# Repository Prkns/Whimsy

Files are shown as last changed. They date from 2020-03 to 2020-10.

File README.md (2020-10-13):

# Whimsy - Rev0.21

A 40% keyboard with exposed Elite-C/OLED and Rotary encoder.

My first attempt at designing a "proper" custom keyboard. I spent far too long looking at all the amazing new PCB's and custom keyboards being released and having a massive urge to do one for myself. Here is my first attempt.

I've not taken delivery of the physical PCBs as of yet so i can't comment on how well i did, but they will be with me shortly.

**STILL IN DEVELOPMENT - NOT READY FOR PRODUCTION - DO NOT ORDER**

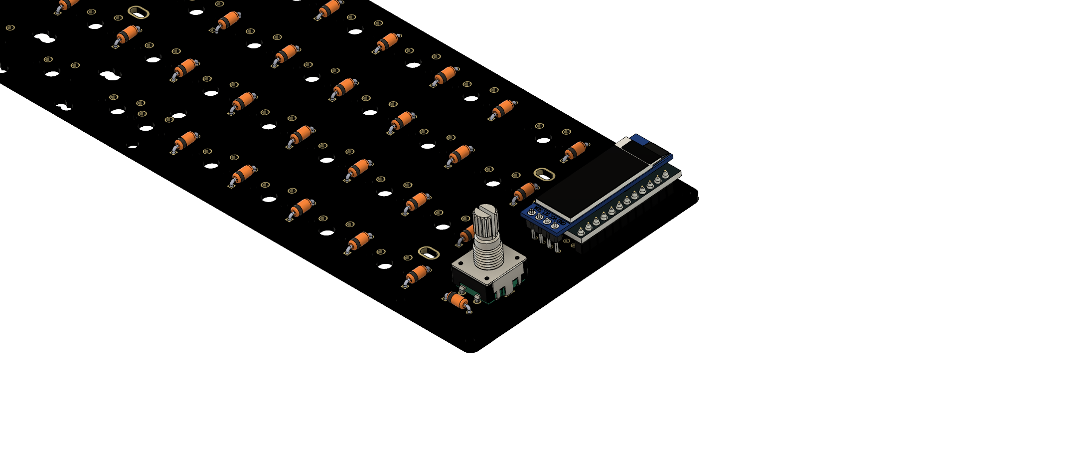
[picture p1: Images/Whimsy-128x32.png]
Whimsy


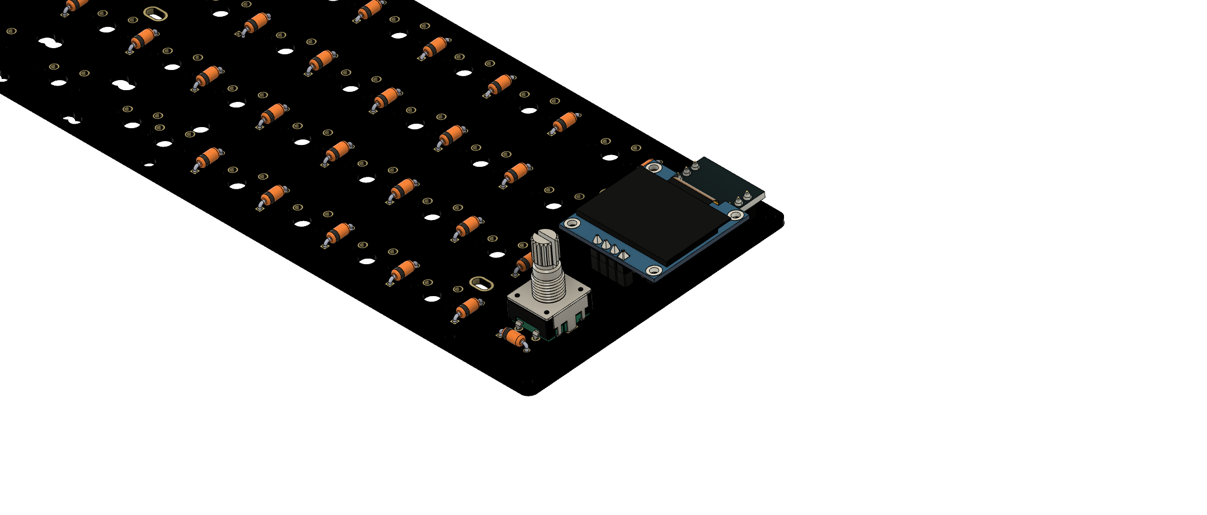
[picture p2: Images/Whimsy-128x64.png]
Whimsy


---

### Plans 🤔

**rev1:** A working version of the board and an FR4 sandwich case

**rev2:** Tidied up traces and an acrylic case

---

#### Say hi 👋

If you're interested in any aspect of this board or want to point out anything that could be done better in a more private manner, head on over to my [website](https://prkns.me/) and you'll find a few different methods on there.

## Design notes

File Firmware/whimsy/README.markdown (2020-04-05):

# Whimsy!



Whimsy is the Most Extra 40% keyboard I could think of. It is designed by [David Perkins](https://prkns.me/), who apparently takes every ridiculous idea
as a personal challenge. The layout is currently based heavily on the incredible UT47.2, but with an added rotary encoder, and OLED.

## Updates

### 2020-03-16
v0 PCBs have arrived and are awaiting additional supplies to be built and tested.

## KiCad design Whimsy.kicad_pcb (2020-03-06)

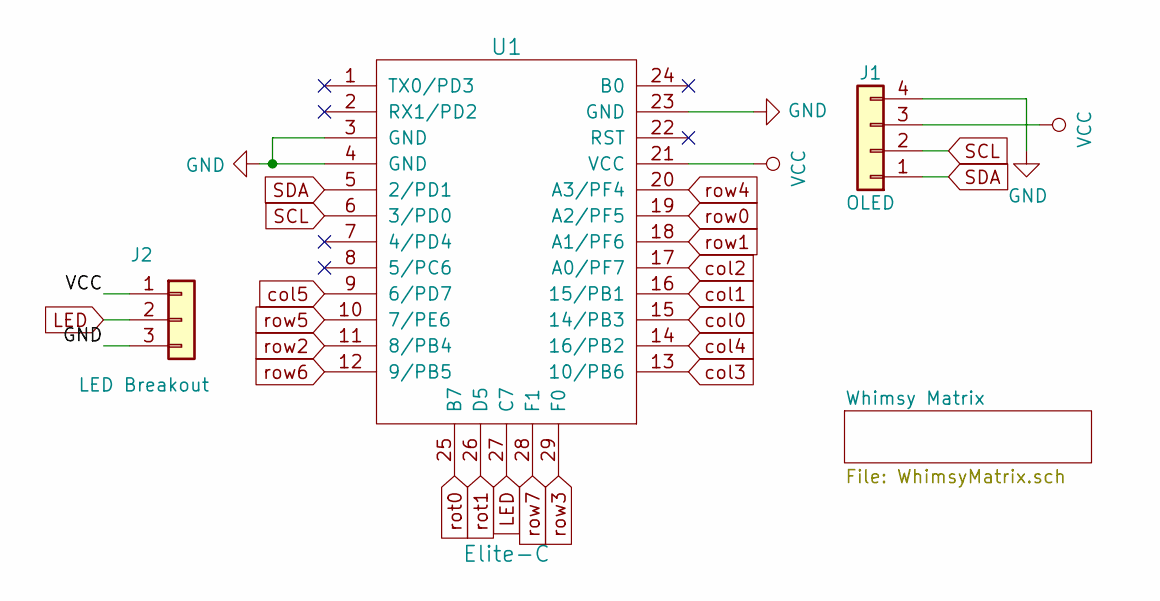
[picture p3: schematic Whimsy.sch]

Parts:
J1: OLED; OLED_4Pin
J2: LED Breakout; LED
U1: Elite-C; Elite-C-NoSilk

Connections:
GND: J1.4, J2.3, U1.3 (GND), U1.4 (GND), U1.23 (GND); also elsewhere on the board
LED: J2.2, U1.27 (C7)
SCL: J1.2, U1.6 (3/PD0)
SDA: J1.1, U1.5 (2/PD1)
VCC: J1.3, J2.1, U1.21 (VCC)
col0: U1.15 (14/PB3); also elsewhere on the board
col1: U1.16 (15/PB1); also elsewhere on the board
col2: U1.17 (A0/PF7); also elsewhere on the board
col3: U1.13 (10/PB6); also elsewhere on the board
col4: U1.14 (16/PB2); also elsewhere on the board
col5: U1.9 (6/PD7); also elsewhere on the board
rot0: U1.25 (B7); also elsewhere on the board
rot1: U1.26 (D5); also elsewhere on the board
row0: U1.19 (A2/PF5); also elsewhere on the board
row1: U1.18 (A1/PF6); also elsewhere on the board
row2: U1.11 (8/PB4); also elsewhere on the board
row3: U1.29 (F0); also elsewhere on the board
row4: U1.20 (A3/PF4); also elsewhere on the board
row5: U1.10 (7/PE6); also elsewhere on the board
row6: U1.12 (9/PB5); also elsewhere on the board
row7: U1.28 (F1); also elsewhere on the board

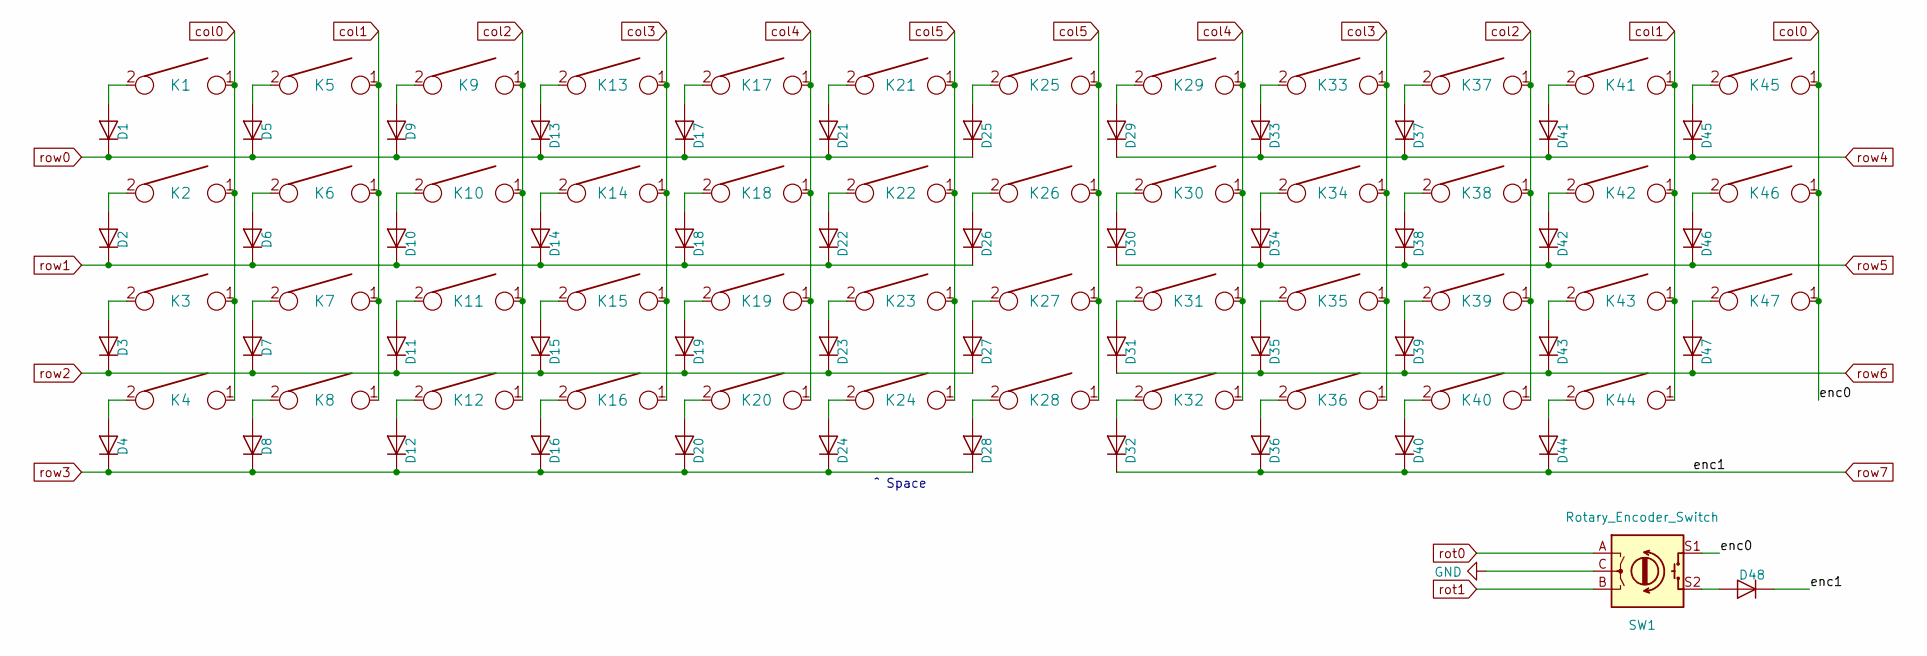
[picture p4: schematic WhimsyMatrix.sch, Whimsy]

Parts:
D1, D2, D3, D4, D5, D6, D7, D8, D9, D10, D11, D12, D13, D14, D15, D16, D17, D18, D19, D20, D21, D22, D23, D24, D25, D26, D27, D28, D29, D30, D31, D32, D33, D34, D35, D36, D37, D38, D39, D40, D41, D42, D43, D44, D45, D46, D47, D48: D; Diode-Hybrid-Back
K1, K4, K5, K6, K7, K8, K9, K10, K11, K12, K13, K14, K15, K16, K17, K18, K19, K21, K22, K23, K25, K26, K27, K29, K30, K31, K32, K33, K34, K35, K36, K37, K38, K39, K40, K41, K42, K43, K44, K47: KEYSW; Mx_Alps_100
K2, K20, K28, K46: KEYSW; Mx_Alps_125
K3, K45: KEYSW; Mx_Alps_150
K24: KEYSW; Mx_Alps_200
SW1: Rotary_Encoder_Switch; RotaryEncoder_Alps_EC11E-Switch_Vertical_H20mm-keebio_modif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

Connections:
GND: SW1.C; also elsewhere on the board
unnamed: D1.2 (A), K1.2
unnamed: D2.2 (A), K2.2
unnamed: D3.2 (A), K3.2
unnamed: D4.2 (A), K4.2
unnamed: D5.2 (A), K5.2
unnamed: D6.2 (A), K6.2
unnamed: D7.2 (A), K7.2
unnamed: D8.2 (A), K8.2
unnamed: D9.2 (A), K9.2
unnamed: D10.2 (A), K10.2
unnamed: D11.2 (A), K11.2
unnamed: D12.2 (A), K12.2
unnamed: D13.2 (A), K13.2
unnamed: D14.2 (A), K14.2
unnamed: D15.2 (A), K15.2
unnamed: D16.2 (A), K16.2
unnamed: D17.2 (A), K17.2
unnamed: D18.2 (A), K18.2
unnamed: D19.2 (A), K19.2
unnamed: D20.2 (A), K20.2
unnamed: D21.2 (A), K21.2
unnamed: D22.2 (A), K22.2
unnamed: D23.2 (A), K23.2
unnamed: D24.2 (A), K24.2
unnamed: D25.2 (A), K25.2
unnamed: D26.2 (A), K26.2
unnamed: D27.2 (A), K27.2
unnamed: D28.2 (A), K28.2
unnamed: D29.2 (A), K29.2
unnamed: D30.2 (A), K30.2
unnamed: D31.2 (A), K31.2
unnamed: D32.2 (A), K32.2
unnamed: D33.2 (A), K33.2
unnamed: D34.2 (A), K34.2
unnamed: D35.2 (A), K35.2
unnamed: D36.2 (A), K36.2
unnamed: D37.2 (A), K37.2
unnamed: D38.2 (A), K38.2
unnamed: D39.2 (A), K39.2
unnamed: D40.2 (A), K40.2
unnamed: D41.2 (A), K41.2
unnamed: D42.2 (A), K42.2
unnamed: D43.2 (A), K43.2
unnamed: D44.2 (A), K44.2
unnamed: D45.2 (A), K45.2
unnamed: D46.2 (A), K46.2
unnamed: D47.2 (A), K47.2
unnamed: D48.2 (A), SW1.S2
col0: K1.1, K2.1, K3.1, K4.1, K45.1, K46.1, K47.1, SW1.S1; also elsewhere on the board
col1: K5.1, K6.1, K7.1, K8.1, K41.1, K42.1, K43.1, K44.1; also elsewhere on the board
col2: K9.1, K10.1, K11.1, K12.1, K37.1, K38.1, K39.1, K40.1; also elsewhere on the board
col3: K13.1, K14.1, K15.1, K16.1, K33.1, K34.1, K35.1, K36.1; also elsewhere on the board
col4: K17.1, K18.1, K19.1, K20.1, K29.1, K30.1, K31.1, K32.1; also elsewhere on the board
col5: K21.1, K22.1, K23.1, K24.1, K25.1, K26.1, K27.1, K28.1; also elsewhere on the board
rot0: SW1.A; also elsewhere on the board
rot1: SW1.B; also elsewhere on the board
row0: D1.1 (K), D5.1 (K), D9.1 (K), D13.1 (K), D17.1 (K), D21.1 (K), D25.1 (K); also elsewhere on the board
row1: D2.1 (K), D6.1 (K), D10.1 (K), D14.1 (K), D18.1 (K), D22.1 (K), D26.1 (K); also elsewhere on the board
row2: D3.1 (K), D7.1 (K), D11.1 (K), D15.1 (K), D19.1 (K), D23.1 (K), D27.1 (K); also elsewhere on the board
row3: D4.1 (K), D8.1 (K), D12.1 (K), D16.1 (K), D20.1 (K), D24.1 (K), D28.1 (K); also elsewhere on the board
row4: D29.1 (K), D33.1 (K), D37.1 (K), D41.1 (K), D45.1 (K); also elsewhere on the board
row5: D30.1 (K), D34.1 (K), D38.1 (K), D42.1 (K), D46.1 (K); also elsewhere on the board
row6: D31.1 (K), D35.1 (K), D39.1 (K), D43.1 (K), D47.1 (K); also elsewhere on the board
row7: D32.1 (K), D36.1 (K), D40.1 (K), D44.1 (K), D48.1 (K); also elsewhere on the board

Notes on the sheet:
^ Space

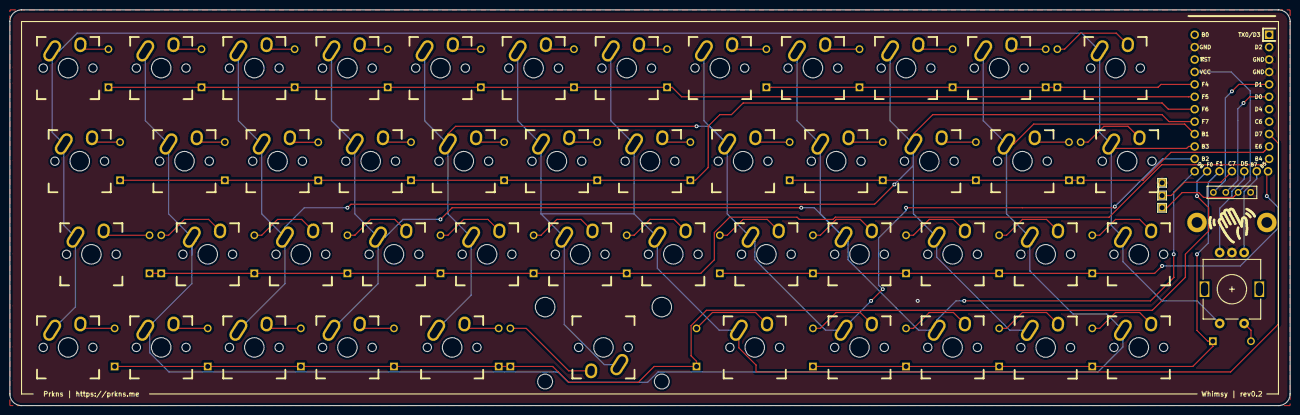
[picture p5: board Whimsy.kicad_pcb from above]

Board: 2 copper layers, 261.9 x 81.0 mm, 102 parts (1 on the bottom side), 69 nets.

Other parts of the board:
TH1, TH1#2: HOLE; M2_HOLE_PCB
Wave: Wave

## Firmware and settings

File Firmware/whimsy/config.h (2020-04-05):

#ifndef CONFIG_H
#define CONFIG_H

#include "config_common.h"

/* USB Device descriptor parameter */
#define VENDOR_ID       0xFEED
#define PRODUCT_ID      0x6060
#define DEVICE_VER      0x0001
#define MANUFACTURER    qmkbuilder
#define PRODUCT         keyboard
#define DESCRIPTION     Keyboard

/* key matrix size */
#define MATRIX_ROWS 8
#define MATRIX_COLS 6

#define ENCODER_RESOLUTION 2
#define ENCODERS_PAD_A { D5 }
#define ENCODERS_PAD_B { B7 }

/* key matrix pins */
#define MATRIX_ROW_PINS { F5, F6, B4, F0, F4, E6, B5, F1 }
#define MATRIX_COL_PINS { B3, B1, F7, B6, B2, D7 }
#define UNUSED_PINS

/* COL2ROW or ROW2COL */
#define DIODE_DIRECTION COL2ROW

/* number of backlight levels */

#ifdef BACKLIGHT_PIN
#define BACKLIGHT_LEVELS 3
#endif

/* Set 0 if debouncing isn't needed */
#define DEBOUNCING_DELAY 5

/* Mechanical locking support. Use KC_LCAP, KC_LNUM or KC_LSCR instead in keymap */
#define LOCKING_SUPPORT_ENABLE

/* Locking resynchronize hack */
#define LOCKING_RESYNC_ENABLE

/* key combination for command */
#define IS_COMMAND() ( \
    keyboard_report->mods == (MOD_BIT(KC_LSHIFT) | MOD_BIT(KC_RSHIFT)) \
)

/* prevent stuck modifiers */
#define PREVENT_STUCK_MODIFIERS

#define RGB_DI_PIN C7
#ifdef RGB_DI_PIN
#define RGBLIGHT_ANIMATIONS
#define RGBLED_NUM 8
#define RGBLIGHT_HUE_STEP 8
#define RGBLIGHT_SAT_STEP 8
#define RGBLIGHT_VAL_STEP 8
#endif

#endif

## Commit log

2020-03-03 added elite-c, changed switch matrix to groups, added LED breakout, added off board reset switch, added OLED pins
    [Whimsy.sch, WhimsyMatrix.sch]
2020-03-03 duplicate diode (D28) fixed
    [Whimsy.sch, WhimsyMatrix.sch]
2020-03-03 first layout test
    [Whimsy.sch, WhimsyMatrix.sch]
2020-03-04 properly laid out keys, cut edges
    [Whimsy.kicad_pcb, WhimsyMatrix.sch]
2020-03-04 added all diodes, new render, all cut corners
    [Whimsy.kicad_pcb]
2020-03-05 started routing traces, finishing rev0.1
    [Whimsy.kicad_pcb, WhimsyMatrix.sch]
2020-03-05 better routing, columns, rows and via's to connect to the elite c
    [Whimsy.kicad_pcb, Whimsy.sch, WhimsyMatrix.sch]
2020-03-05 first fully routed/traced board
    [Whimsy.kicad_pcb]
2020-03-06 gnd pins were not working as inteded, solder mask was a little off, fixed overall matrix, tightened the schematic to make it more logical
    [Whimsy.kicad_pcb, Whimsy.sch, WhimsyMatrix.sch]
2020-03-06 flipped the elite-c, re-routed a lot of the board, tidied up some traces, new render, updated readme
    [Whimsy.kicad_pcb, Whimsy.sch]
2020-03-06 fixed gnd net
    [Whimsy.kicad_pcb]
2020-03-06 issue with front mask
    [Whimsy.kicad_pcb]
2020-03-07 gerbers, directory management, file naming
    [Whimsy.sch, WhimsyMatrix.sch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]
2020-03-07 complete gerbers, bottom plate case, final renders, project clean-up
    [Whimsy.sch, WhimsyMatrix.sch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]
2020-03-19 case ideas
2020-03-19 rev0.3 production ready
    [Whimsy-B_Cu.gbl, Whimsy-B_Mask.gbs, Whimsy-Edge_Cuts.gm1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]
2020-04-05 updated PCB design
    [Whimsy.sch, WhimsyMatrix.sch]
2020-10-13 removed v1 case files
2020-10-13 removed sandwich case
    in preparation for final release
    [WhimsyBottomPlate-B_Cu.gbl, WhimsyBottomPlate-B_Mask.gbs, WhimsyBottomPlate-Edge_Cuts.gm1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]
2020-10-13 new v0.3 PCB renders
